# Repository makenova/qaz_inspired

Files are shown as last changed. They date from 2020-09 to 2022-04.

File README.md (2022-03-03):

# qaz_inspired

My take on a qaz inspired boards. Mostly the difference is integrated mcu.

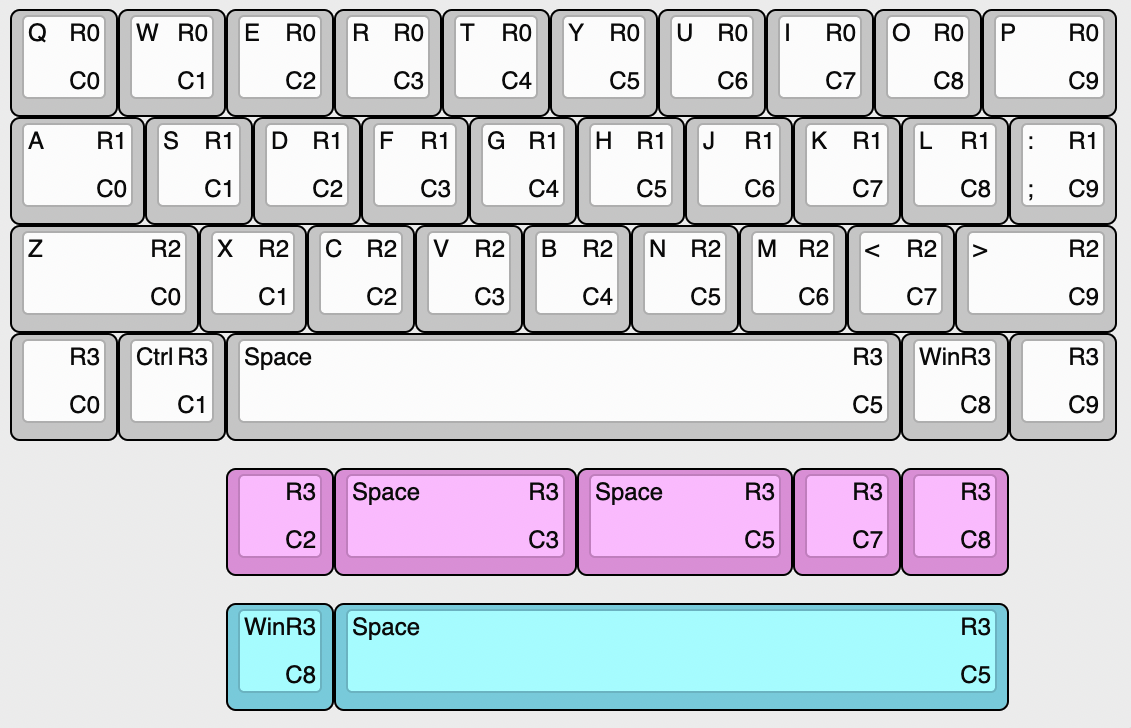
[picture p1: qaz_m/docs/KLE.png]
KLE Diagram


## qaz_m **untested**

- integrated mcu
- shifted bottom row

## qazv4n_m **untested**

- integrated mcu
- hotswap
- shifted bottom row
- removable gamer row

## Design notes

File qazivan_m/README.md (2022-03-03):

# qaziv4n

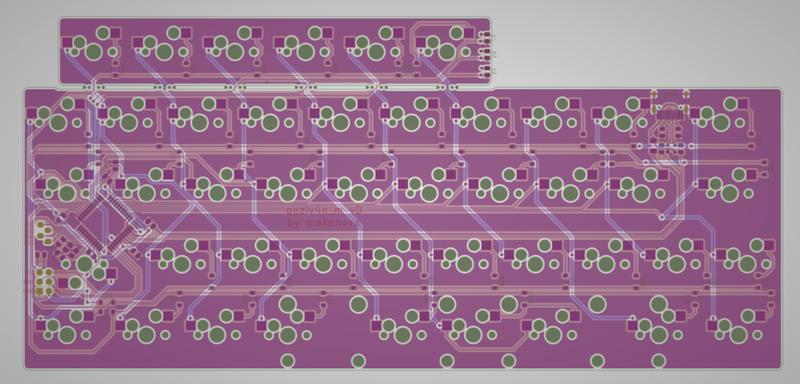
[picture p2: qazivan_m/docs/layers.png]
layers


My take on an integrated mcu hot-swap [qaz](https://www.cbkbd.com/product/qaz-keyboard-kit) with a [van](https://trashman.wiki/en/keyboards/v4n4g0n) backspace and gamer row.

The plate file can be found in the [docs](./docs) folder.

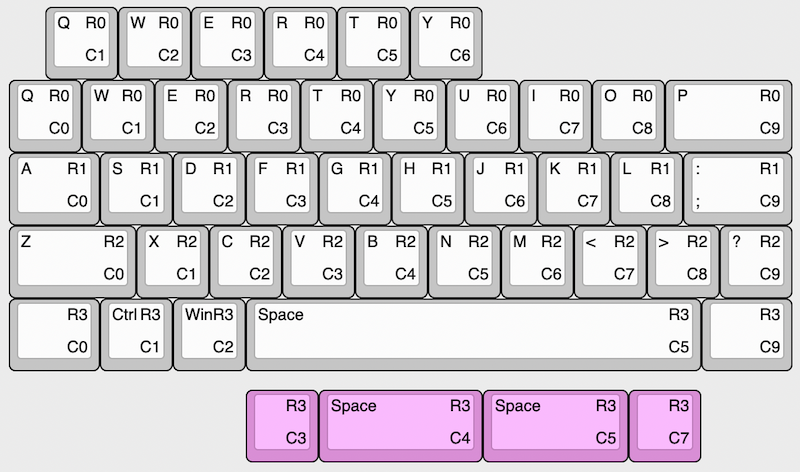
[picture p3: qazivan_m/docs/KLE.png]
KLE Diagram


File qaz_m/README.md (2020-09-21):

# qaz_b
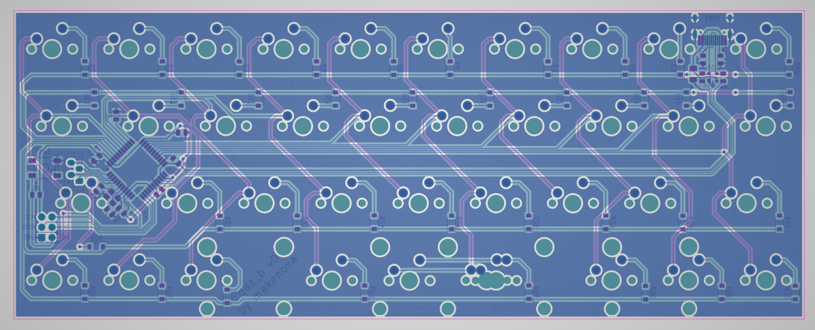
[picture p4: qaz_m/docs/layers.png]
layers


My take on the qaz. It has an integrated mcu and one more bottom row layout.

The plate file can be found in the [docs](./docs) folder.

KLE Diagram

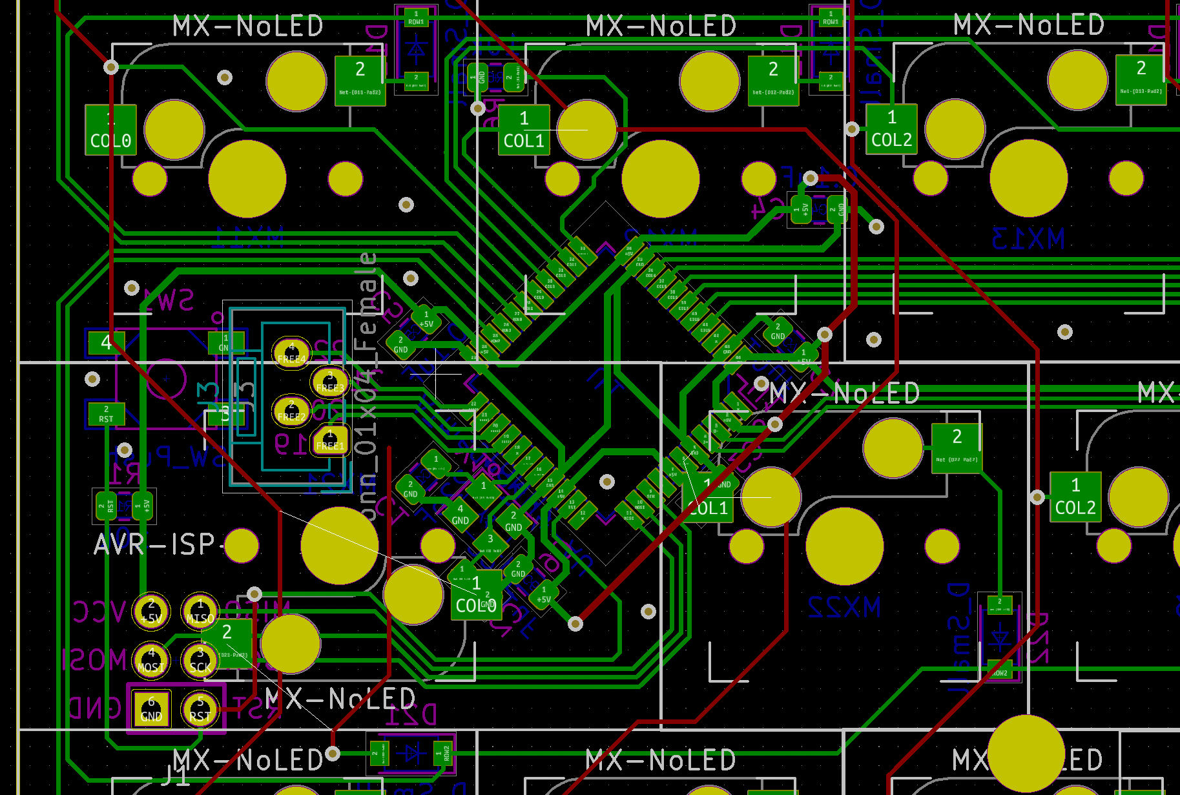
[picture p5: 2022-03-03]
qazivan_m/docs/ref/Screen Shot 2022-03-01 at 9.24.45 PM.png

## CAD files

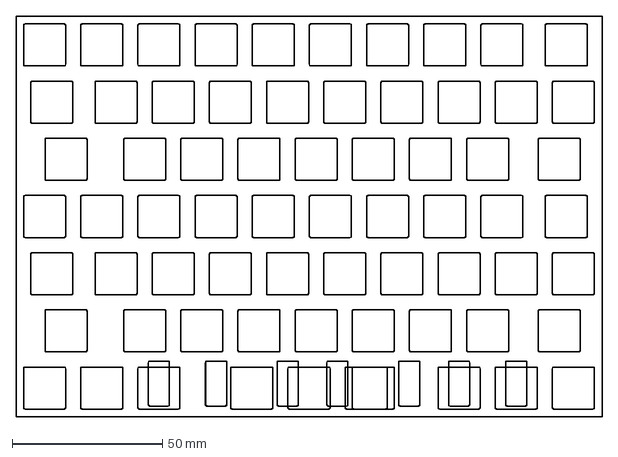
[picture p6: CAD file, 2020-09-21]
qaz_m/docs/plate-20200908-223126.dxf
195.3 x 133.3 mm

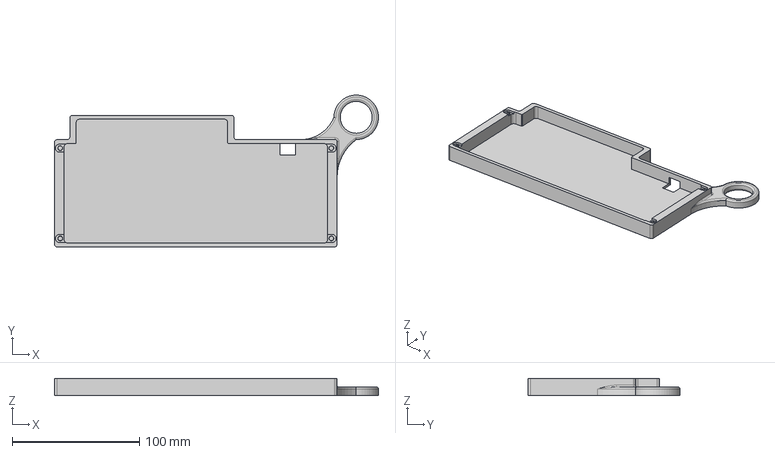
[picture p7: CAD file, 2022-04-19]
qazivan_m/docs/case/case.step
254.3 x 119.2 x 13.6 mm

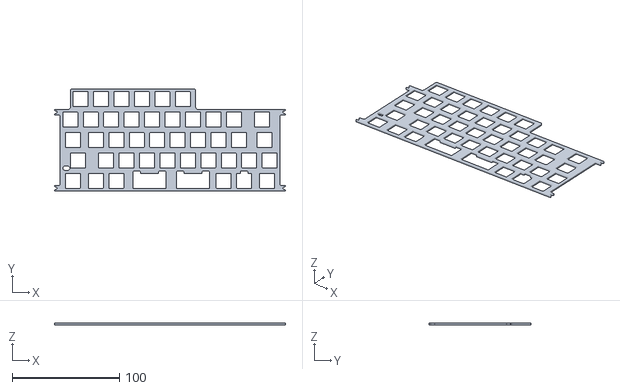
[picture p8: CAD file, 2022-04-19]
qazivan_m/docs/plate/qaziv4n_hull_plate.stl
215.3 x 95.2 x 1.60

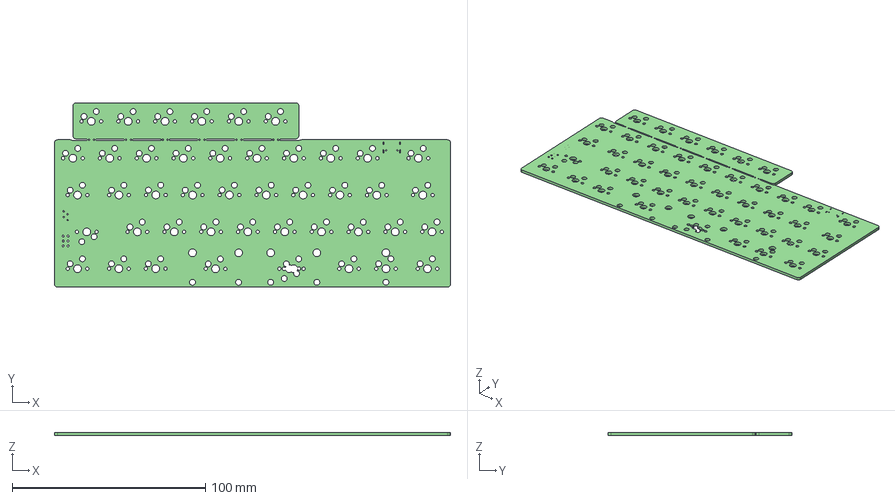
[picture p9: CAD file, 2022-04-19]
qazivan_m/docs/qazivan_m.step
204.8 x 95.2 x 1.60 mm

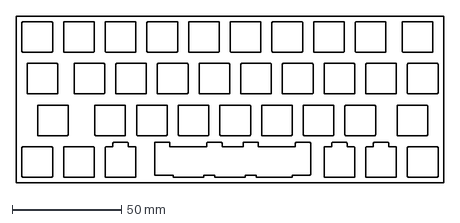
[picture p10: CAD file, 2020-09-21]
qaz_m/docs/plate_clean.dxf
195.3 x 76.2 mm

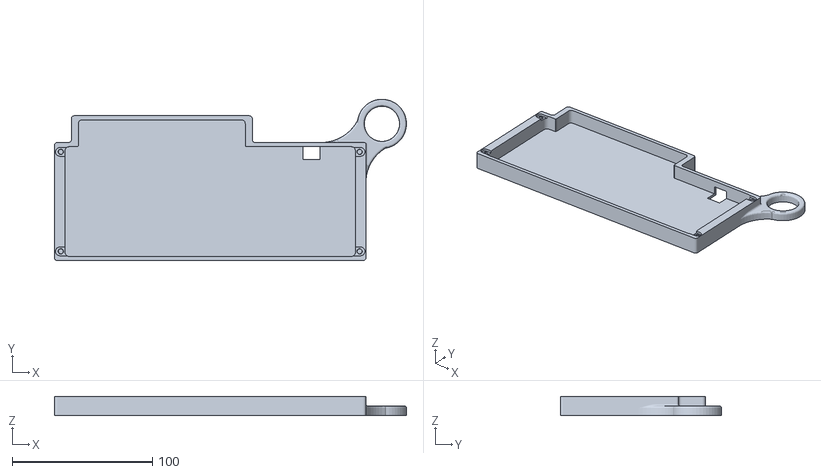
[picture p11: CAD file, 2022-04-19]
qazivan_m/docs/case/qaziv4n_case.stl
250.7 x 115.0 x 13.6

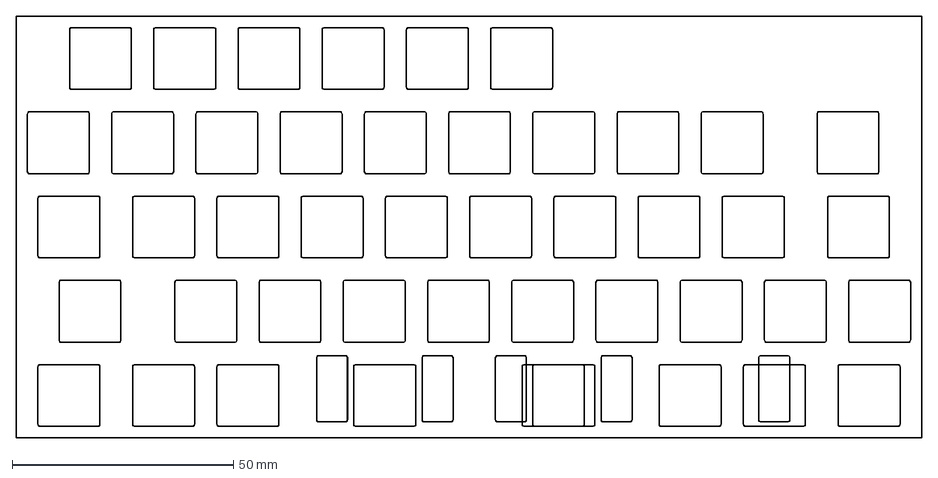
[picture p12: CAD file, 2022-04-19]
qazivan_m/docs/plate/qaziv4n_plate_raw.dxf
204.8 x 95.2 mm

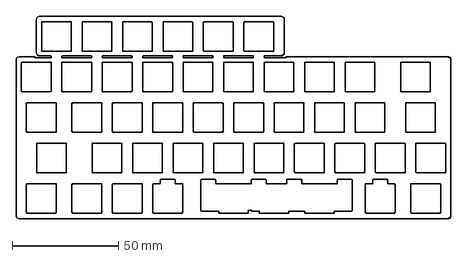
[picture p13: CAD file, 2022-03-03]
qazivan_m/docs/plate/qaziv4n_plate_clean.dxf
204.8 x 95.3 mm

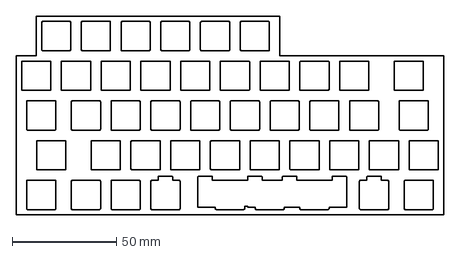
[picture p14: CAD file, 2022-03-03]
qazivan_m/docs/plate/qaziv4n_plate_shaped.dxf
204.8 x 95.2 mm

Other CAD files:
qazivan_m/docs/plate/plate.3mf
qazivan_m/docs/case/case.3mf
qazivan_m/docs/case/case.stl
qazivan_m/docs/plate/qaziv4n_hull_plate.dxf

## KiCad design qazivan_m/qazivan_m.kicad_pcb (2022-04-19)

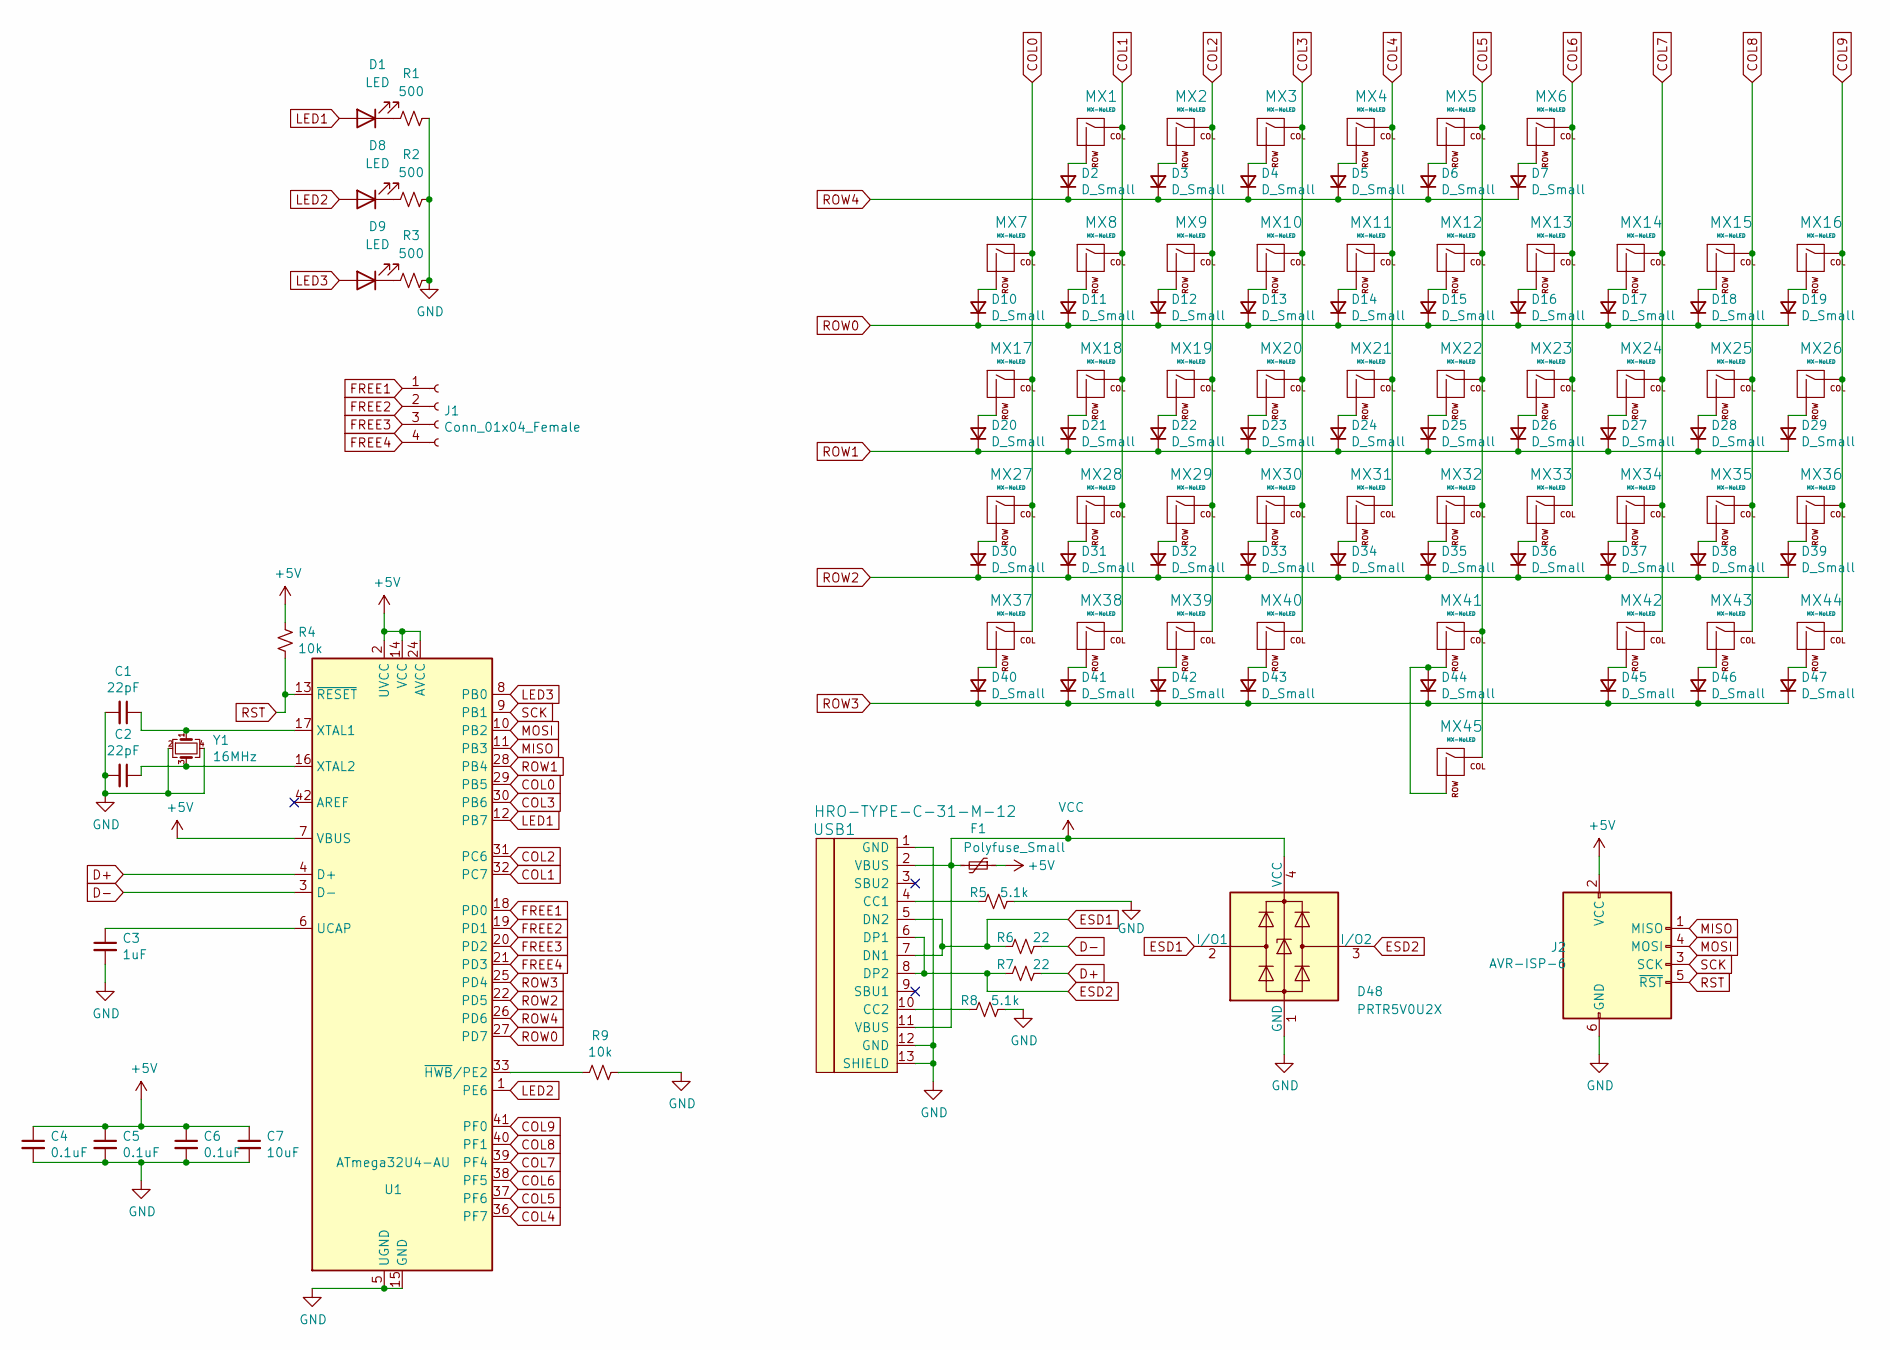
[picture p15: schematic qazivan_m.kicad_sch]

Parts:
C1, C2: 22pF; C_0805_2012Metric; LCSC C1804
C3: 1uF; C_0805_2012Metric; LCSC C28323
C4, C5, C6: 0.1uF; C_0805_2012Metric; LCSC C49678
C7: 10uF; C_0805_2012Metric; LCSC C307523
D1, D8, D9: LED; LED_0805_2012Metric
D2, D3, D4, D5, D6, D7, D10, D11, D12, D13, D14, D15, D16, D17, D18, D19, D20, D21, D22, D23, D24, D25, D26, D27, D28, D29, D30, D31, D32, D33, D34, D35, D36, D37, D38, D39, D40, D41, D42, D43, D44, D45, D46, D47: D_Small; D_SOD-123; LCSC C81598
D48: PRTR5V0U2X; SOT143B; LCSC C78442
F1: Polyfuse_Small; Fuse_1206_3216Metric; LCSC C151162
J1: Conn_01x04_Female; JST_ZE_B04B-ZESK-D_1x04_P1.50mm_Vertical
J2: AVR-ISP-6; Reset_Pretty
MX1, MX2, MX3, MX4, MX5, MX6, MX7, MX8, MX9, MX10, MX11, MX12, MX13, MX14, MX15, MX18, MX19, MX20, MX21, MX22, MX23, MX24, MX25, MX28, MX29, MX30, MX31, MX32, MX33, MX34, MX35, MX36, MX38, MX39, MX42, MX43: MX-NoLED; MXOnly-1U-Hotswap
MX16, MX27: MX-NoLED; MXOnly-1.75U-Hotswap
MX17, MX37, MX44: MX-NoLED; MXOnly-1.25U-Hotswap
MX26: MX-NoLED; MXOnly-1.5U-Hotswap
MX40: MX-NoLED; MXOnly-2.25U-Hotswap-ReversedStabilizers
MX41: MX-NoLED; MXOnly-2U-Hotswap-ReversedStabilizers
MX45: MX-NoLED; MXOnly-6.25U-Hotswap-ReversedStabilizers
R1, R2, R3: 500; R_0805_2012Metric
R4, R9: 10k; R_0805_2012Metric; LCSC C17414
R5, R8: 5.1k; R_0805_2012Metric; LCSC C27834
R6, R7: 22; R_0805_2012Metric; LCSC C17561
U1: ATmega32U4-AU; TQFP-44_10x10mm_P0.8mm; LCSC C44854
USB1: HRO-TYPE-C-31-M-12; HRO-TYPE-C-31-M-12-HandSoldering
Y1: 16MHz; Crystal_SMD_3225-4Pin_3.2x2.5mm; LCSC C89379

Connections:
+5V: C4.1, C5.1, C6.1, C7.1, F1.1, J2.2 (VCC), R4.1, U1.2 (UVCC), U1.7 (VBUS), U1.14 (VCC), U1.24 (AVCC), U1.34 (VCC), U1.44 (AVCC)
COL0: MX7.1 (COL), MX17.1 (COL), MX27.1 (COL), MX37.1 (COL), U1.29 (PB5)
COL1: MX1.1 (COL), MX8.1 (COL), MX18.1 (COL), MX28.1 (COL), MX38.1 (COL), U1.32 (PC7)
COL2: MX2.1 (COL), MX9.1 (COL), MX19.1 (COL), MX29.1 (COL), MX39.1 (COL), U1.31 (PC6)
COL3: MX3.1 (COL), MX10.1 (COL), MX20.1 (COL), MX30.1 (COL), MX40.1 (COL), U1.30 (PB6)
COL4: MX4.1 (COL), MX11.1 (COL), MX21.1 (COL), MX31.1 (COL), U1.36 (PF7)
COL5: MX5.1 (COL), MX12.1 (COL), MX22.1 (COL), MX32.1 (COL), MX41.1 (COL), MX45.1 (COL), U1.37 (PF6)
COL6: MX6.1 (COL), MX13.1 (COL), MX23.1 (COL), MX33.1 (COL), U1.38 (PF5)
COL7: MX14.1 (COL), MX24.1 (COL), MX34.1 (COL), MX42.1 (COL), U1.39 (PF4)
COL8: MX15.1 (COL), MX25.1 (COL), MX35.1 (COL), MX43.1 (COL), U1.40 (PF1)
COL9: MX16.1 (COL), MX26.1 (COL), MX36.1 (COL), MX44.1 (COL), U1.41 (PF0)
D+: R7.1, U1.4 (D+)
D-: R6.1, U1.3 (D-)
ESD1: D48.2 (I/O1), R6.2, USB1.5 (DN2), USB1.7 (DN1)
ESD2: D48.3 (I/O2), R7.2, USB1.6 (DP1), USB1.8 (DP2)
FREE1: J1.1, U1.18 (PD0)
FREE2: J1.2, U1.19 (PD1)
FREE3: J1.3, U1.20 (PD2)
FREE4: J1.4, U1.21 (PD3)
GND: C1.2, C2.2, C3.2, C4.2, C5.2, C6.2, C7.2, D48.1 (GND), J2.6 (GND), R1.2, R2.2, R3.2, R5.1, R8.1, R9.1, U1.5 (UGND), U1.15 (GND), U1.23 (GND), U1.35 (GND), U1.43 (GND), USB1.1 (GND), USB1.12 (GND), USB1.13 (SHIELD), Y1.2, Y1.4
LED1: D1.2 (A), U1.12 (PB7)
LED2: D8.2 (A), U1.1 (PE6)
LED3: D9.2 (A), U1.8 (PB0)
MISO: J2.1 (MISO), U1.11 (PB3)
MOSI: J2.4 (MOSI), U1.10 (PB2)
unnamed: C1.1, U1.17 (XTAL1), Y1.1
unnamed: C2.1, U1.16 (XTAL2), Y1.3
unnamed: C3.1, U1.6 (UCAP)
unnamed: D1.1 (K), R1.1
unnamed: D2.2 (A), MX1.2 (ROW)
unnamed: D3.2 (A), MX2.2 (ROW)
unnamed: D4.2 (A), MX3.2 (ROW)
unnamed: D5.2 (A), MX4.2 (ROW)
unnamed: D6.2 (A), MX5.2 (ROW)
unnamed: D7.2 (A), MX6.2 (ROW)
unnamed: D8.1 (K), R2.1
unnamed: D9.1 (K), R3.1
unnamed: D10.2 (A), MX7.2 (ROW)
unnamed: D11.2 (A), MX8.2 (ROW)
unnamed: D12.2 (A), MX9.2 (ROW)
unnamed: D13.2 (A), MX10.2 (ROW)
unnamed: D14.2 (A), MX11.2 (ROW)
unnamed: D15.2 (A), MX12.2 (ROW)
unnamed: D16.2 (A), MX13.2 (ROW)
unnamed: D17.2 (A), MX14.2 (ROW)
unnamed: D18.2 (A), MX15.2 (ROW)
unnamed: D19.2 (A), MX16.2 (ROW)
unnamed: D20.2 (A), MX17.2 (ROW)
unnamed: D21.2 (A), MX18.2 (ROW)
unnamed: D22.2 (A), MX19.2 (ROW)
unnamed: D23.2 (A), MX20.2 (ROW)
unnamed: D24.2 (A), MX21.2 (ROW)
unnamed: D25.2 (A), MX22.2 (ROW)
unnamed: D26.2 (A), MX23.2 (ROW)
unnamed: D27.2 (A), MX24.2 (ROW)
unnamed: D28.2 (A), MX25.2 (ROW)
unnamed: D29.2 (A), MX26.2 (ROW)
unnamed: D30.2 (A), MX27.2 (ROW)
unnamed: D31.2 (A), MX28.2 (ROW)
unnamed: D32.2 (A), MX29.2 (ROW)
unnamed: D33.2 (A), MX30.2 (ROW)
unnamed: D34.2 (A), MX31.2 (ROW)
unnamed: D35.2 (A), MX32.2 (ROW)
unnamed: D36.2 (A), MX33.2 (ROW)
unnamed: D37.2 (A), MX34.2 (ROW)
unnamed: D38.2 (A), MX35.2 (ROW)
unnamed: D39.2 (A), MX36.2 (ROW)
unnamed: D40.2 (A), MX37.2 (ROW)
unnamed: D41.2 (A), MX38.2 (ROW)
unnamed: D42.2 (A), MX39.2 (ROW)
unnamed: D43.2 (A), MX40.2 (ROW)
unnamed: D44.2 (A), MX41.2 (ROW), MX45.2 (ROW)
unnamed: D45.2 (A), MX42.2 (ROW)
unnamed: D46.2 (A), MX43.2 (ROW)
unnamed: D47.2 (A), MX44.2 (ROW)
unnamed: R5.2, USB1.4 (CC1)
unnamed: R8.2, USB1.10 (CC2)
unnamed: R9.2, U1.33 (~HWB/PE2)
ROW0: D10.1 (K), D11.1 (K), D12.1 (K), D13.1 (K), D14.1 (K), D15.1 (K), D16.1 (K), D17.1 (K), D18.1 (K), D19.1 (K), U1.27 (PD7)
ROW1: D20.1 (K), D21.1 (K), D22.1 (K), D23.1 (K), D24.1 (K), D25.1 (K), D26.1 (K), D27.1 (K), D28.1 (K), D29.1 (K), U1.28 (PB4)
ROW2: D30.1 (K), D31.1 (K), D32.1 (K), D33.1 (K), D34.1 (K), D35.1 (K), D36.1 (K), D37.1 (K), D38.1 (K), D39.1 (K), U1.22 (PD5)
ROW3: D40.1 (K), D41.1 (K), D42.1 (K), D43.1 (K), D44.1 (K), D45.1 (K), D46.1 (K), D47.1 (K), U1.25 (PD4)
ROW4: D2.1 (K), D3.1 (K), D4.1 (K), D5.1 (K), D6.1 (K), D7.1 (K), U1.26 (PD6)
RST: J2.5 (~RST), R4.2, U1.13 (~RESET)
SCK: J2.3 (SCK), U1.9 (PB1)
VCC: D48.4 (VCC), F1.2, USB1.2 (VBUS), USB1.11 (VBUS)

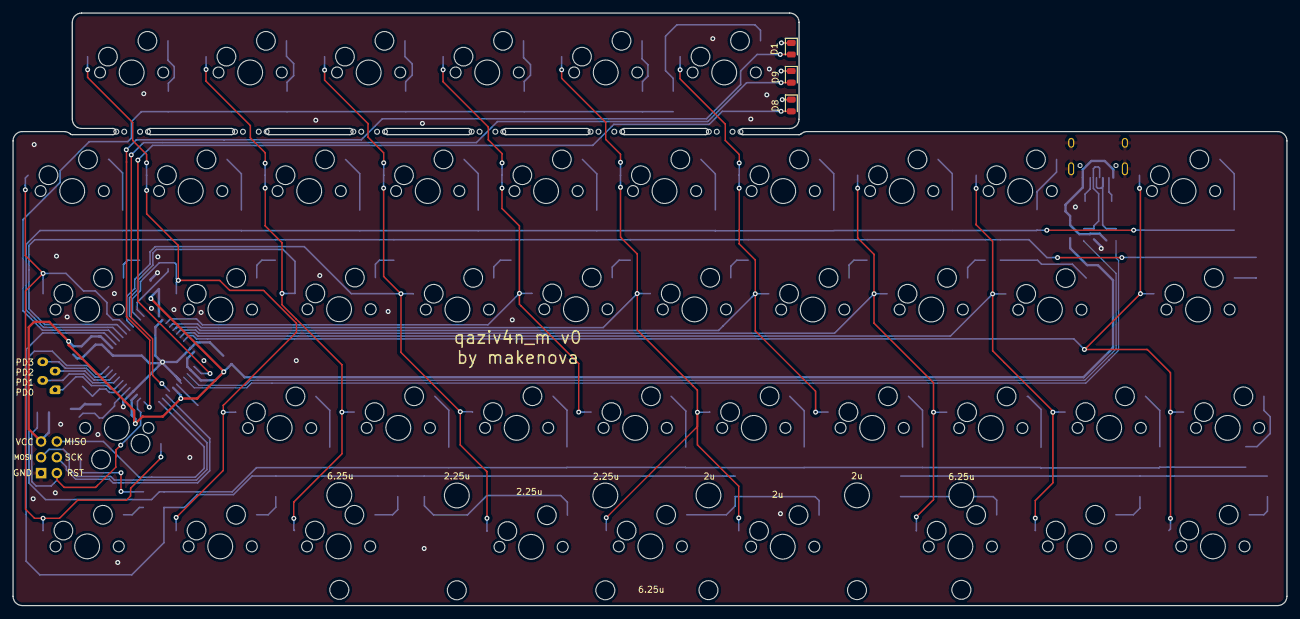
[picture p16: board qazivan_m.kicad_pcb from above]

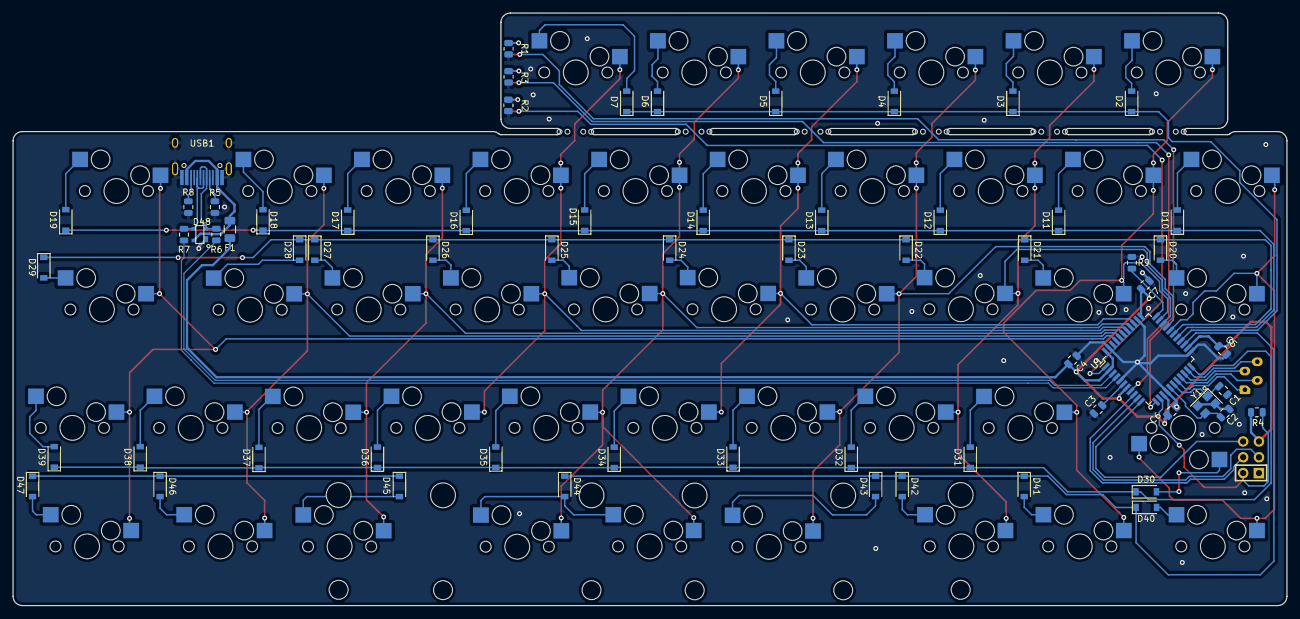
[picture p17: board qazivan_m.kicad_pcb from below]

Board: 2 copper layers, 204.8 x 95.2 mm, 115 parts (66 on the bottom side), 86 nets.

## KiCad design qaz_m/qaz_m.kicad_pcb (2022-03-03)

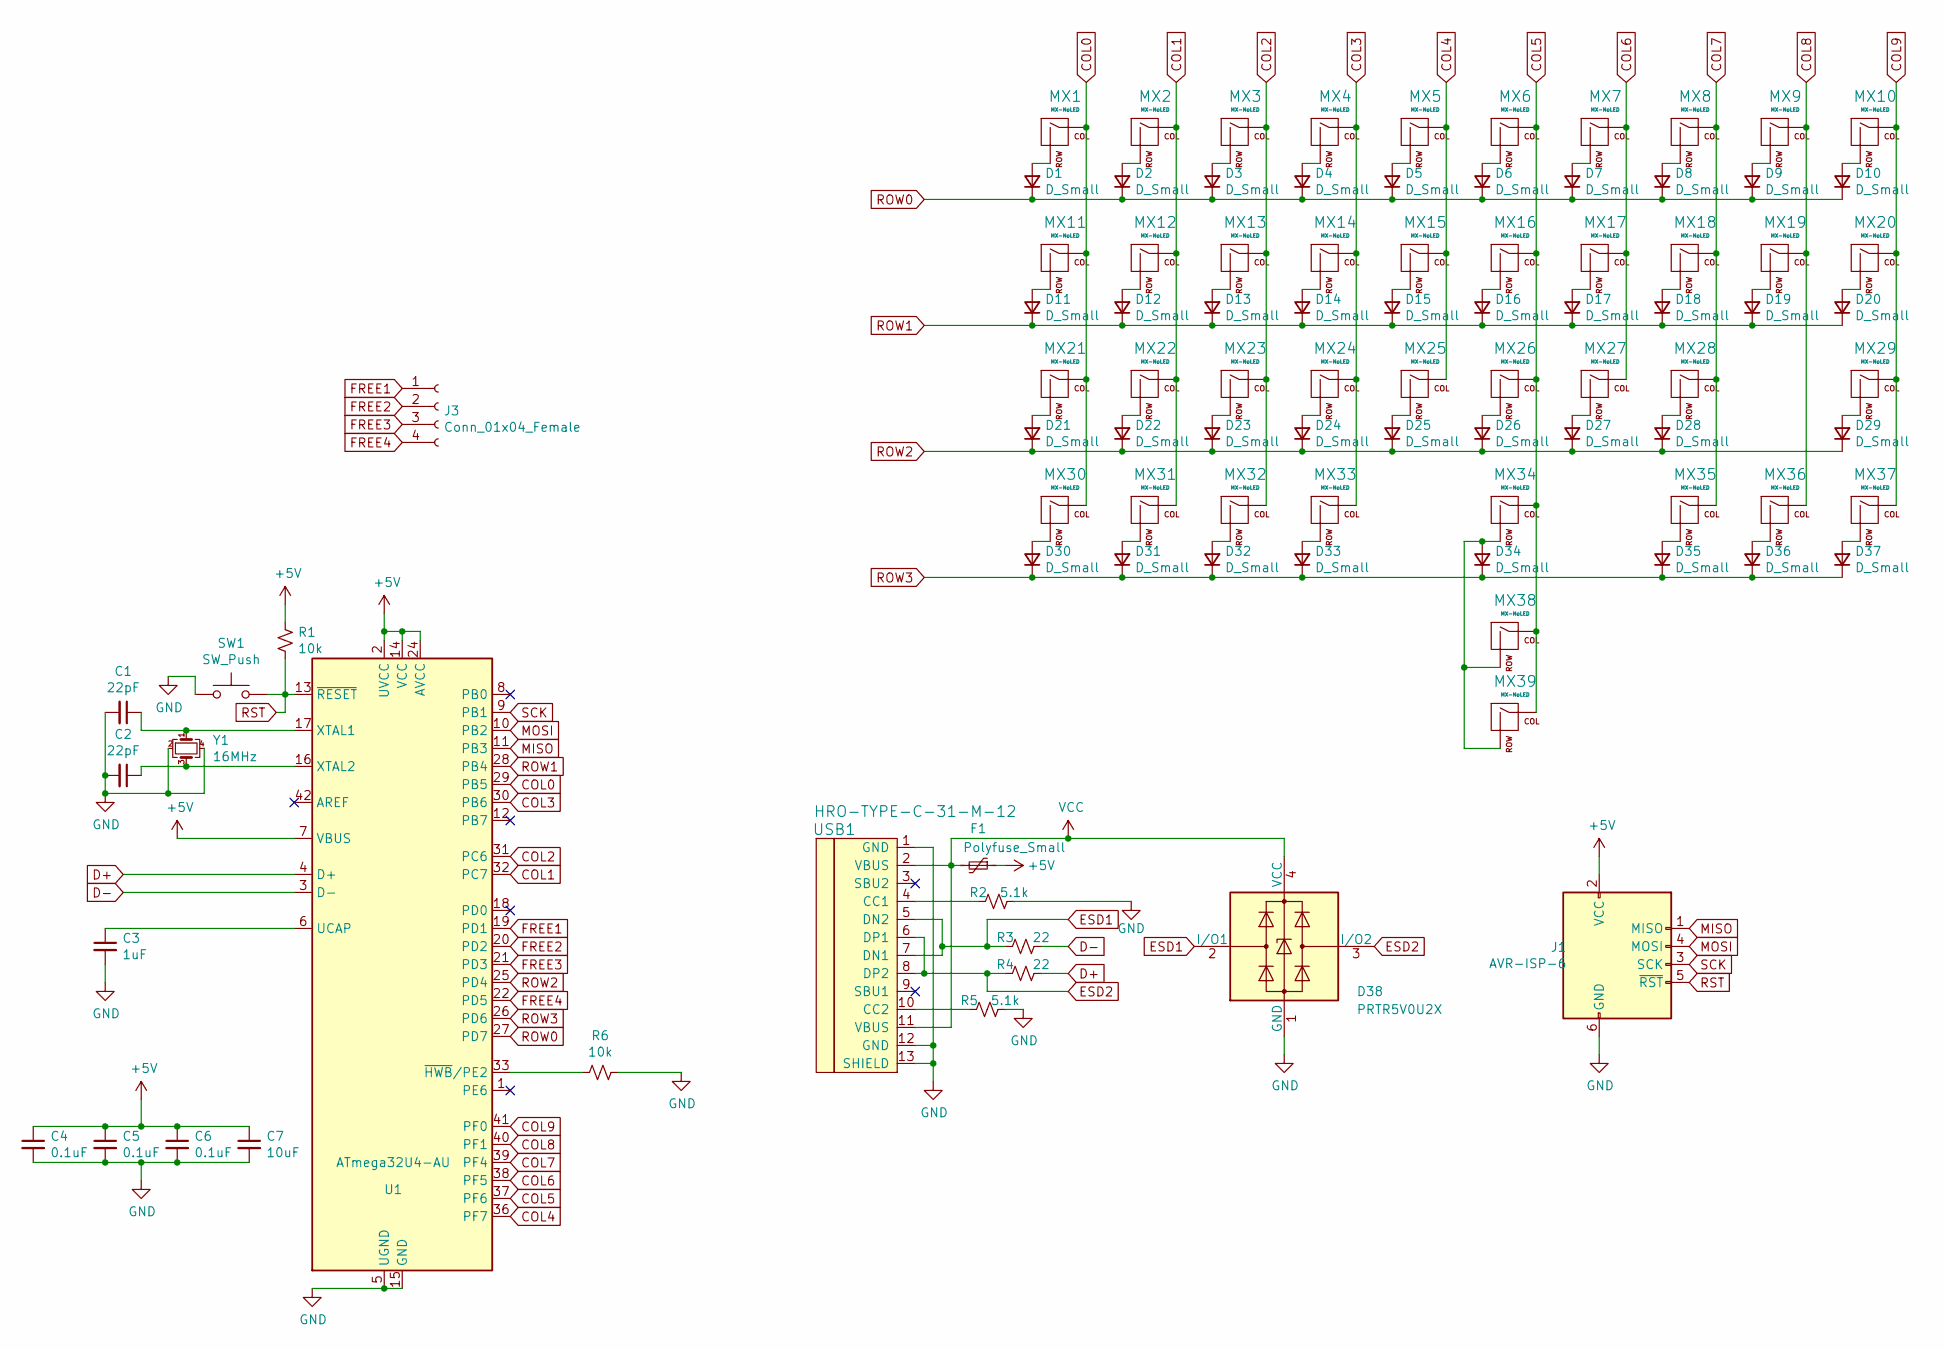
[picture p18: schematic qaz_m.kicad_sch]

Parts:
C1, C2: 22pF; C_0805_2012Metric; LCSC C1804
C3: 1uF; C_0805_2012Metric; LCSC C28323
C4, C5, C6: 0.1uF; C_0805_2012Metric; LCSC C49678
C7: 10uF; C_0805_2012Metric; LCSC C307523
D1, D2, D3, D4, D5, D6, D7, D8, D9, D10, D11, D12, D13, D14, D15, D16, D17, D18, D19, D20, D21, D22, D23, D24, D25, D26, D27, D28, D29, D30, D31, D32, D33, D34, D35, D36, D37: D_Small; D_SOD-123; LCSC C81598
D38: PRTR5V0U2X; SOT143B; LCSC C78442
F1: Polyfuse_Small; Fuse_1206_3216Metric; LCSC C151162
J1: AVR-ISP-6; Reset_Pretty
J3: Conn_01x04_Female; JST_ZE_B04B-ZESK-D_1x04_P1.50mm_Vertical
MX1, MX2, MX3, MX4, MX5, MX6, MX7, MX8, MX9, MX12, MX13, MX14, MX15, MX16, MX17, MX18, MX19, MX20, MX22, MX23, MX24, MX25, MX26, MX27, MX28, MX30, MX31, MX32, MX35, MX36, MX37: MX-NoLED; MXOnly-1U-NoLED
MX10, MX11: MX-NoLED; MXOnly-1.25U-NoLED
MX21: MX-NoLED; MXOnly-1.75U-NoLED
MX29: MX-NoLED; MXOnly-1.5U-NoLED
MX33: MX-NoLED; MXOnly-2.25U-ReversedStabilizers-NoLED
MX34: MX-NoLED; MXOnly-2U-ReversedStabilizers-NoLED
MX38, MX39: MX-NoLED; MXOnly-6.25U-ReversedStabilizers-NoLED
R1, R6: 10k; R_0805_2012Metric; LCSC C17414
R2, R5: 5.1k; R_0805_2012Metric; LCSC C27834
R3, R4: 22; R_0805_2012Metric; LCSC C17561
SW1: SW_Push; SKQG-1155865; LCSC C318884
U1: ATmega32U4-AU; TQFP-44_10x10mm_P0.8mm; LCSC C44854
USB1: HRO-TYPE-C-31-M-12; HRO-TYPE-C-31-M-12-HandSoldering
Y1: 16MHz; Crystal_SMD_3225-4Pin_3.2x2.5mm; LCSC C89379

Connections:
+5V: C4.1, C5.1, C6.1, C7.1, F1.1, J1.2 (VCC), R1.1, U1.2 (UVCC), U1.7 (VBUS), U1.14 (VCC), U1.24 (AVCC), U1.34 (VCC), U1.44 (AVCC)
COL0: MX1.1 (COL), MX11.1 (COL), MX21.1 (COL), MX30.1 (COL), U1.29 (PB5)
COL1: MX2.1 (COL), MX12.1 (COL), MX22.1 (COL), MX31.1 (COL), U1.32 (PC7)
COL2: MX3.1 (COL), MX13.1 (COL), MX23.1 (COL), MX32.1 (COL), U1.31 (PC6)
COL3: MX4.1 (COL), MX14.1 (COL), MX24.1 (COL), MX33.1 (COL), U1.30 (PB6)
COL4: MX5.1 (COL), MX15.1 (COL), MX25.1 (COL), U1.36 (PF7)
COL5: MX6.1 (COL), MX16.1 (COL), MX26.1 (COL), MX34.1 (COL), MX38.1 (COL), MX39.1 (COL), U1.37 (PF6)
COL6: MX7.1 (COL), MX17.1 (COL), MX27.1 (COL), U1.38 (PF5)
COL7: MX8.1 (COL), MX18.1 (COL), MX28.1 (COL), MX35.1 (COL), U1.39 (PF4)
COL8: MX9.1 (COL), MX19.1 (COL), MX36.1 (COL), U1.40 (PF1)
COL9: MX10.1 (COL), MX20.1 (COL), MX29.1 (COL), MX37.1 (COL), U1.41 (PF0)
D+: R4.1, U1.4 (D+)
D-: R3.1, U1.3 (D-)
ESD1: D38.2 (I/O1), R3.2, USB1.5 (DN2), USB1.7 (DN1)
ESD2: D38.3 (I/O2), R4.2, USB1.6 (DP1), USB1.8 (DP2)
FREE1: J3.1, U1.19 (PD1)
FREE2: J3.2, U1.20 (PD2)
FREE3: J3.3, U1.21 (PD3)
FREE4: J3.4, U1.22 (PD5)
GND: C1.2, C2.2, C3.2, C4.2, C5.2, C6.2, C7.2, D38.1 (GND), J1.6 (GND), R2.1, R5.1, R6.1, SW1.1, U1.5 (UGND), U1.15 (GND), U1.23 (GND), U1.35 (GND), U1.43 (GND), USB1.1 (GND), USB1.12 (GND), USB1.13 (SHIELD), Y1.2, Y1.4
MISO: J1.1 (MISO), U1.11 (PB3)
MOSI: J1.4 (MOSI), U1.10 (PB2)
unnamed: C1.1, U1.17 (XTAL1), Y1.1
unnamed: C2.1, U1.16 (XTAL2), Y1.3
unnamed: C3.1, U1.6 (UCAP)
unnamed: D1.2 (A), MX1.2 (ROW)
unnamed: D2.2 (A), MX2.2 (ROW)
unnamed: D3.2 (A), MX3.2 (ROW)
unnamed: D4.2 (A), MX4.2 (ROW)
unnamed: D5.2 (A), MX5.2 (ROW)
unnamed: D6.2 (A), MX6.2 (ROW)
unnamed: D7.2 (A), MX7.2 (ROW)
unnamed: D8.2 (A), MX8.2 (ROW)
unnamed: D9.2 (A), MX9.2 (ROW)
unnamed: D10.2 (A), MX10.2 (ROW)
unnamed: D11.2 (A), MX11.2 (ROW)
unnamed: D12.2 (A), MX12.2 (ROW)
unnamed: D13.2 (A), MX13.2 (ROW)
unnamed: D14.2 (A), MX14.2 (ROW)
unnamed: D15.2 (A), MX15.2 (ROW)
unnamed: D16.2 (A), MX16.2 (ROW)
unnamed: D17.2 (A), MX17.2 (ROW)
unnamed: D18.2 (A), MX18.2 (ROW)
unnamed: D19.2 (A), MX19.2 (ROW)
unnamed: D20.2 (A), MX20.2 (ROW)
unnamed: D21.2 (A), MX21.2 (ROW)
unnamed: D22.2 (A), MX22.2 (ROW)
unnamed: D23.2 (A), MX23.2 (ROW)
unnamed: D24.2 (A), MX24.2 (ROW)
unnamed: D25.2 (A), MX25.2 (ROW)
unnamed: D26.2 (A), MX26.2 (ROW)
unnamed: D27.2 (A), MX27.2 (ROW)
unnamed: D28.2 (A), MX28.2 (ROW)
unnamed: D29.2 (A), MX29.2 (ROW)
unnamed: D30.2 (A), MX30.2 (ROW)
unnamed: D31.2 (A), MX31.2 (ROW)
unnamed: D32.2 (A), MX32.2 (ROW)
unnamed: D33.2 (A), MX33.2 (ROW)
unnamed: D34.2 (A), MX34.2 (ROW), MX38.2 (ROW), MX39.2 (ROW)
unnamed: D35.2 (A), MX35.2 (ROW)
unnamed: D36.2 (A), MX36.2 (ROW)
unnamed: D37.2 (A), MX37.2 (ROW)
unnamed: R2.2, USB1.4 (CC1)
unnamed: R5.2, USB1.10 (CC2)
unnamed: R6.2, U1.33 (~HWB/PE2)
ROW0: D1.1 (K), D2.1 (K), D3.1 (K), D4.1 (K), D5.1 (K), D6.1 (K), D7.1 (K), D8.1 (K), D9.1 (K), D10.1 (K), U1.27 (PD7)
ROW1: D11.1 (K), D12.1 (K), D13.1 (K), D14.1 (K), D15.1 (K), D16.1 (K), D17.1 (K), D18.1 (K), D19.1 (K), D20.1 (K), U1.28 (PB4)
ROW2: D21.1 (K), D22.1 (K), D23.1 (K), D24.1 (K), D25.1 (K), D26.1 (K), D27.1 (K), D28.1 (K), D29.1 (K), U1.25 (PD4)
ROW3: D30.1 (K), D31.1 (K), D32.1 (K), D33.1 (K), D34.1 (K), D35.1 (K), D36.1 (K), D37.1 (K), U1.26 (PD6)
RST: J1.5 (~RST), R1.2, SW1.2, U1.13 (~RESET)
SCK: J1.3 (SCK), U1.9 (PB1)
VCC: D38.4 (VCC), F1.2, USB1.2 (VBUS), USB1.11 (VBUS)

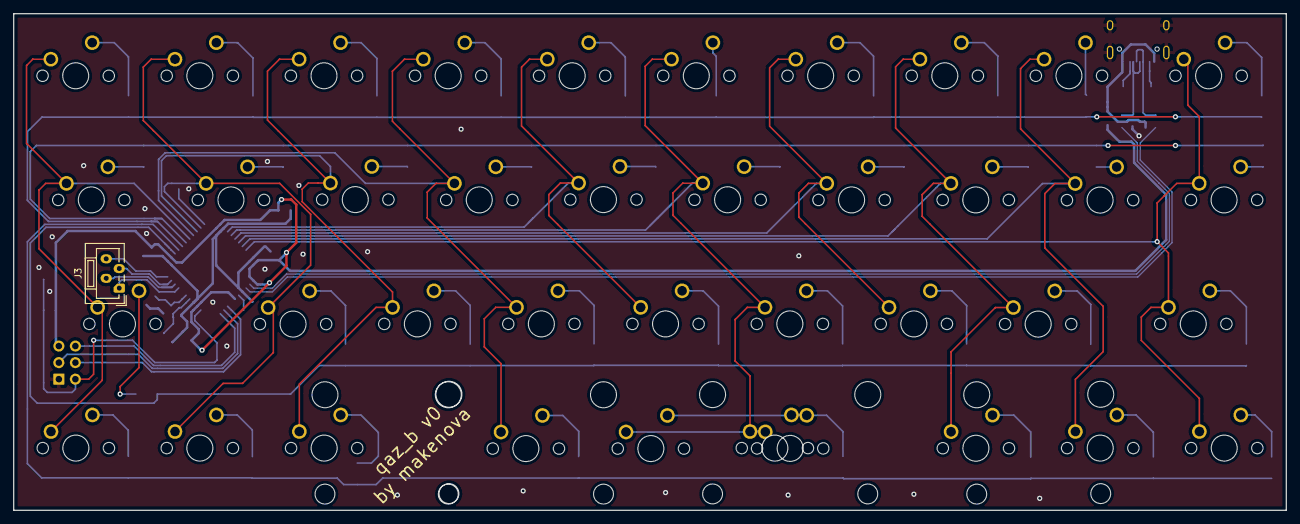
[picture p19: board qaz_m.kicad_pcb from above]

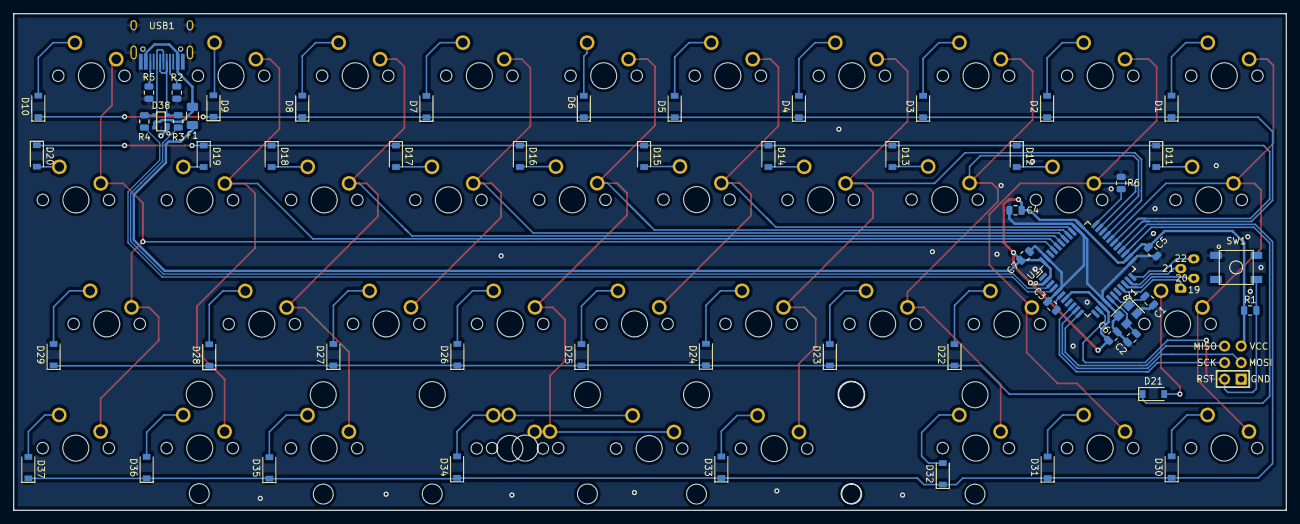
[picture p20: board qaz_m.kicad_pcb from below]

Board: 2 copper layers, 195.3 x 76.2 mm, 97 parts (57 on the bottom side), 72 nets.

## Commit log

2020-09-21 make it so
    note: consider repositioning unused pins breakout so that it is not below a switch.
    [plate-20200908-223126.dxf, plate_clean.dxf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]
2022-03-03 initial draft of qazivan_m
    the bottom rows do not work because of some overlap.
    [plate-20200908-223126.dxf, plate_clean.dxf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]
2022-03-03 fixed bottom row, adding gamer row
    [qazivan_m.kicad_pcb, qazivan_m.kicad_sch]
2022-03-04 add indicator leds. need to figure out mouting
    [qazivan_m-B_Cu.gbr, qazivan_m-B_Mask.gbr, qazivan_m-B_Paste.gbr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]
2022-03-06 fix indicator leds
    mcu pin to anode not cathode
    [qazivan_m-B_Cu.gbr, qazivan_m-B_Mask.gbr, qazivan_m-B_Paste.gbr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]
2022-03-06 update bottom row
    [qazivan_m.kicad_pcb, qazivan_m.kicad_sch]
2022-03-06 generate gerbers
    [qazivan_m-B_Cu.gbr, qazivan_m-B_Mask.gbr, qazivan_m-B_Paste.gbr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]
2022-04-19 center big bar
    [case.3mf, case.step, case.stl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]
